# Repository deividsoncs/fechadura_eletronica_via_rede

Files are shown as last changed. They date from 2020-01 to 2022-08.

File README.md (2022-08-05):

# FechaduraEletronicaREDE
# Fechadura Eletrônica com Abertura por RFID ou LOGIN / SENHA com registro centralizado em bd MySql.

Prosposta desse sistema é automatizar entradas/e ou saída de edificações com acionamento via cartão/tag RFID, 
seguido ou não de entrada de senha via teclado númérico. 

1) Usuário aproxima tag RFID de sensor;
2) Módulo de leitura conectado a rede ethernet faz pesquisa em bd MYSQL;
3) Apresenta mensagem customizada bem-vindo [Fulano] ao portador da tag;
4) Portador da tag regista senha de acesso [opcional]
5) Sistema permite o acesso desbloqueando porta eletromagnética;
6) Log é resgistrado em banco, pessoa, data e hora e porta de acesso.

tecnologias: arduino + módulo ethernet, linguagem C, atuadores (ex.: eletroímã).

@Author: Deividson Calixto da Silva.

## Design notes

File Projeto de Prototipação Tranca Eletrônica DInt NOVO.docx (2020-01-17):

Projeto de Prototipação Tranca Eletrônica DINT.

Objetivo:

Projeto contempla a prototipação de uma fechadura eletrônica, com trava eletromecânica e acionamento por leitura de cartões de acesso (TAGS) RFID e SENHA ou RG e SENHA via teclado numérico, onde os usuários serão registrados em um banco de dados. O controle da entrada dos usuários pode ser visualizado através de um histórico de acesso. Sendo o usuário adicionado em uma lista de usuários relacionado a uma TAG RFID/RG único(s). Gerenciamento de usuários centralizado juntamente com histórico de acessos de entradas.

Funções contempladas:

1) Controle de acesso e histórico de quem entrou na porta N;
2) Controle feito por TAG/RG e Senha individual;
3) Histórico de acessos via aplicação web;
4) Gerenciamento centralizado dos usuários em banco de dados MySQL (Aplicação WEB);
5) Botoeira interna de abertura da porta.

Fluxograma de funcionamento:

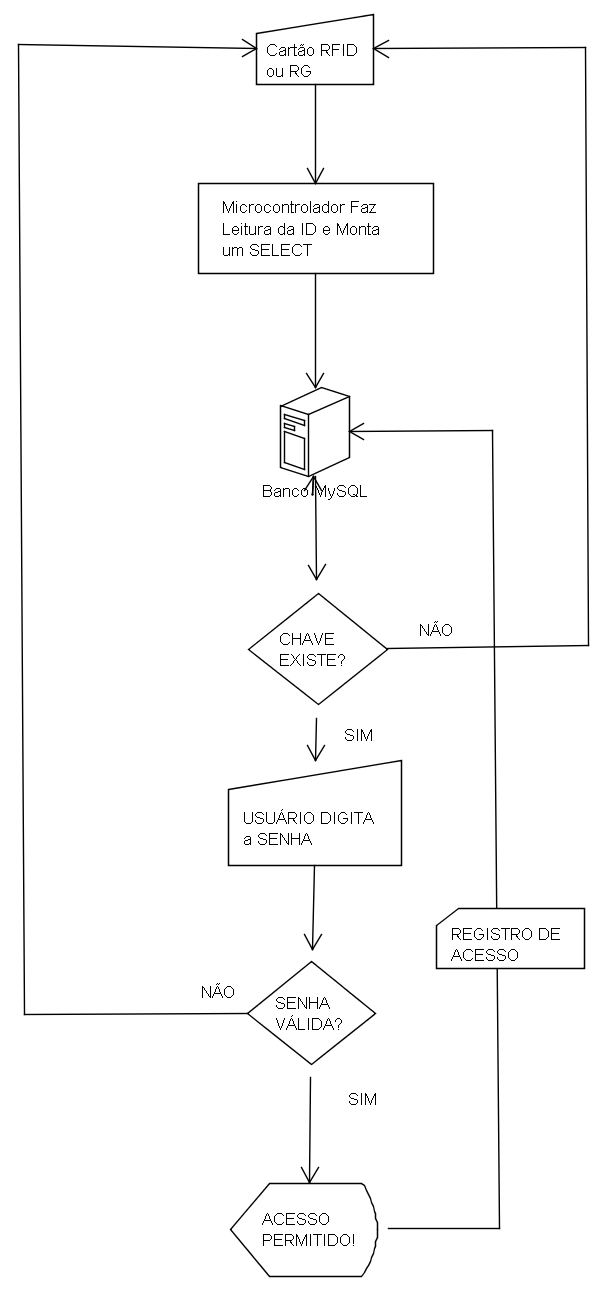
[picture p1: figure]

Imagem 1 - fluxograma

Desenvolvimento:

A) Será desenvolvido um sistema embarcado (Firmware), em linguagem C, para o micro controlador (AtMega2560) realizar as seguintes funções:
1) Leitura de cartão RFID (ou RG) e teclado numérico;
2) Integração do Micro controlador com o protocolo Ethernet, realizando a consulta no banco de retornando com resultado encontrado;
3) Acionamento do relé da fechadura eletromecânica;
4) Criação de uma tabela no banco de dados MySQL (ex.: ID - SENHA NUMERICA – CHAVE RFID – MATRICULA);
5) Registro em Tabela do histórico de entradas.
B) Será desenvolvida uma aplicação web para gerenciamento dos usuários, com as seguintes funcionalidades:
1) Cadastro, edição, exclusão de usuários;
2) Consulta ao histórico de entradas dos usuários;

Exemplo de histórico:

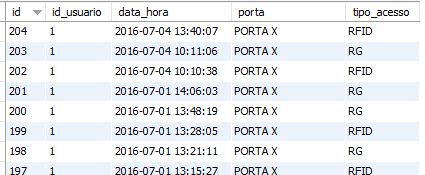
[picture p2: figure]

Imagem 2 - São armazenadas somente as entradas na edificação contemplada.

Dependências necessárias para funcionamento:

1) Rede de intranet DINT(Conexão Ethernet);
2) Servidor de banco de dados MySQL;
3) Alimentação de 12 Vdc, para fechadura eletro mecânica e Microcontrolado e seus afins.

Conclusão:

Projeto proposto contempla um sistema gerenciado e centralizado dos usuários que terão acesso à edificação, possibilitando um histórico das entradas conforme Imagem 2, sistema possibilita entrada de dados por meio do RG ou TAG RFID, atrelado a uma senha de escolha do usuário de 4 dígitos , tornando a aplicação segura e com boa usabilidade, dependendo para sua operação da estabilidade da rede de intranet da DINT, servidor de banco de dados MySQL e Alimentação 12 Vdc. Em casa do falta de energia o acesso se dará por meio da chave. Sendo assim o projeto segue de maneira a providenciar uma solução de baixo custo para o problema proposto, tendo em vista que as soluções do mercado que visam gerenciamento centralizado de usuários são altamente custosas e muita das vezes não vem com todo aparato necessário dependendo de fechaduras eletromagnéticas que são vendidas separadamente, tornando-os ainda mais caros.

Descrição | Quantidade | Imagem

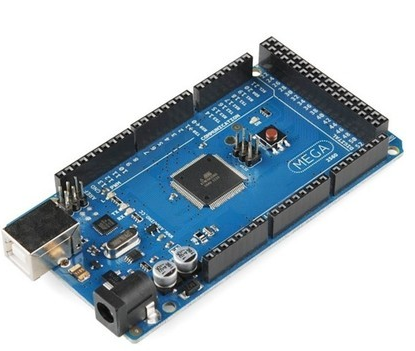
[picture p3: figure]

Arduino Mega 2560 R3 + Cabo Usb para Arduino; Disponível em: http://www.eletrogate.com/pd-88b37-mega-2560-r3-cabo-usb-para-arduino.html?ct=6fb46&p=1&s=1 | 4

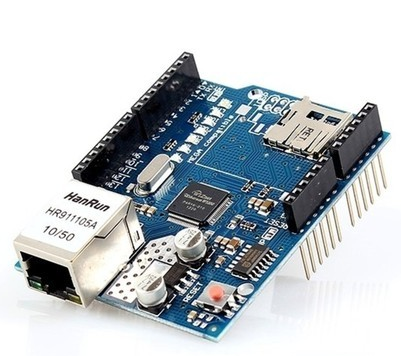
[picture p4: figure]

Ethernet Shield W5100 para Arduino Disponível em: http://www.eletrogate.com/pd-88c9c-ethernet-shield-w5100-para-arduino.html?ct=ae595&p=1&s=1 | 4

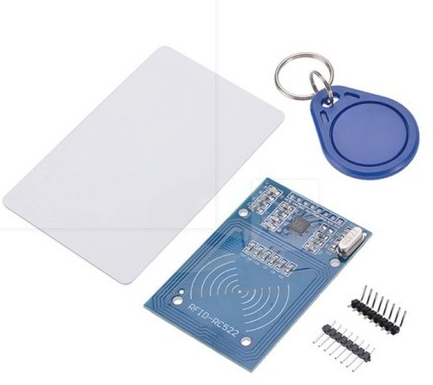
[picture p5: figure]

Kit Módulo Rfid Mfrc522 13,56 Mhz Disponível em: http://www.eletrogate.com/pd-8e3aa-kit-modulo-rfid-mfrc522-13-56-mhz.html?ct=&p=1&s=1 | 4

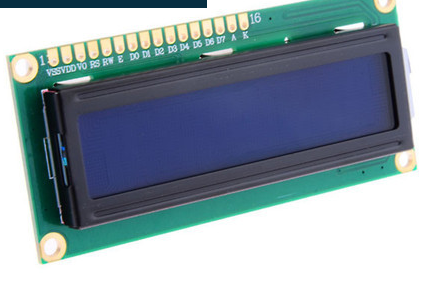
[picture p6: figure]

Display Lcd 16x2 com Backlight | 4
Led Difuso 5mm Amarelo | 4
Led Difuso 5mm Verde | 4
Led Difuso 5mm Vermelho | 4
Diodo Retificador 1N4007 | 4

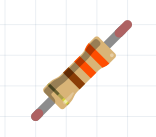
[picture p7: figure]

Resistor 300 Ohms | 12
Resistor 100 Ohms | 8

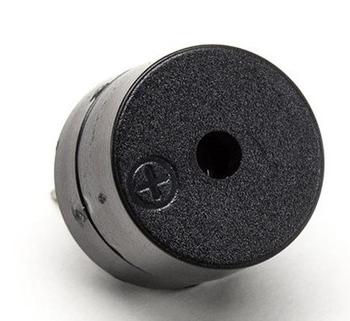
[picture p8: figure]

Buzzer ativo 5 Volts | 4

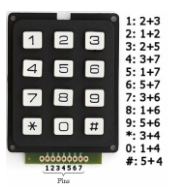
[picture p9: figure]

Teclado Matricial 12 teclas, de 7 Fios/Pinos, Obs.: Não pode ser o tipo membrana, por causa da fragilidade. Disponível em: https://www.robocore.net/modules.php?name=GR_LojaVirtual&prod=164 | 4

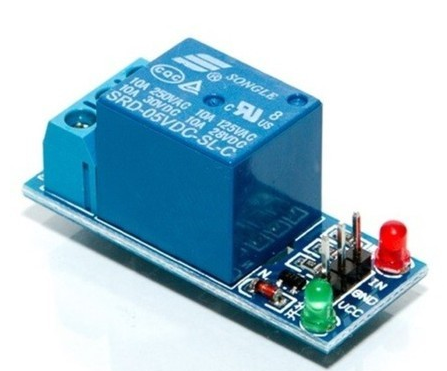
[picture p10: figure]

Módulo Relé 1 Canal 5v Disponível em: http://www.eletrogate.com/pd-1a1bd2-modulo-rele-1-canal-5v.html?ct=&p=1&s=1 | 4

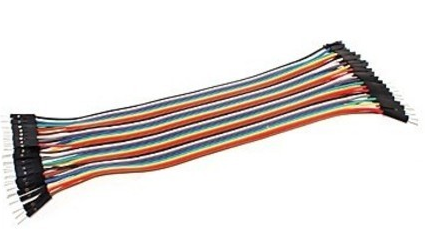
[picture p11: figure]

Fio de 1mm de diâmetro, nas cores AZUL, AMARELO, VERDE, BRANCO e LARANJA | 4 metros de cada

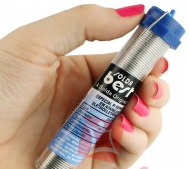
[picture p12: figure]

Estanho para Solda / Fio de Solda 1.0mm - Tubo de 25g | 2

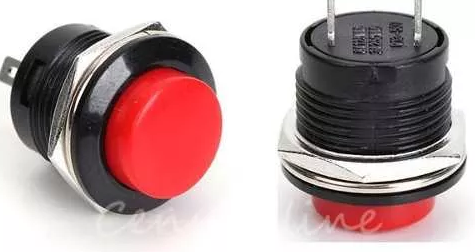
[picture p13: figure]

Botoeira Push Button Normal Aberta 3a 250 V, com rosca | 4

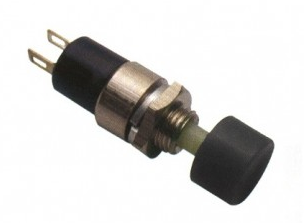
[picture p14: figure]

Chave Push Button Normal Aberta - 2T – Preta, com rosca. | 4
Porta fusível com rabicho + fusível de 1,5A | 4

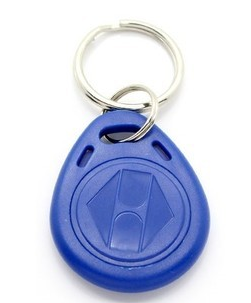
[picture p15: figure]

Tag Chaveiro Rfid Programável Mifare 1k 13,56Mhz Obs.: Atenção com a frequência de 13,56MHz | 120

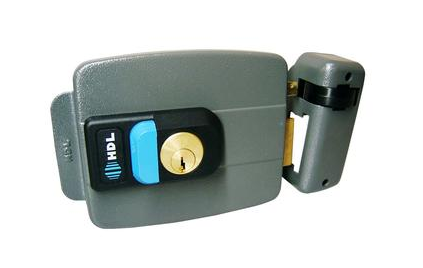
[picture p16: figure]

Fechadura Elétrica Hdl C-90 Dupla com Botao Interno, Porta que abre para dentro. | 3

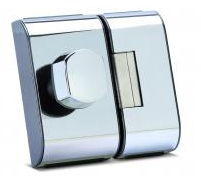
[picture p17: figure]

Fechadura PV-90 2R – Cromada para duas folhas de vidro, com acionamento 12 Vdc, para recorte padrão do mercado, com maçaneta interna. | 1

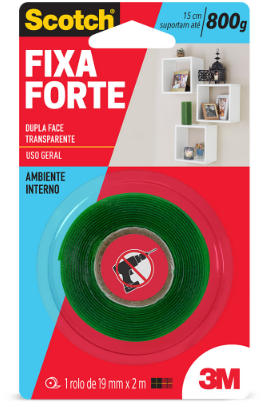
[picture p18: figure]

Fita adesiva dupla face Fixa Forte 19mmx2m | 1

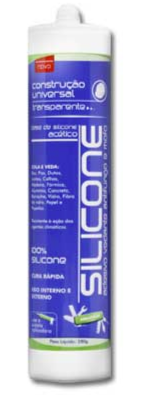
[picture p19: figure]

Silicone Acético Incolor Tubo 280g | 1

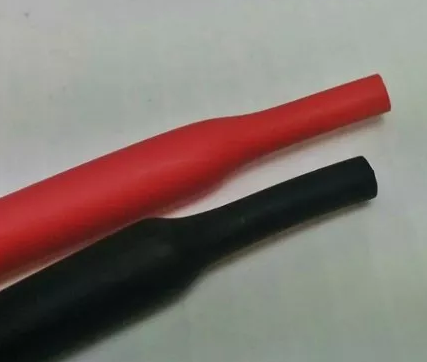
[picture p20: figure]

Espaguetes Isolante Termo Retratil 4mm Vermelho E Preto 5mts | 5 metros

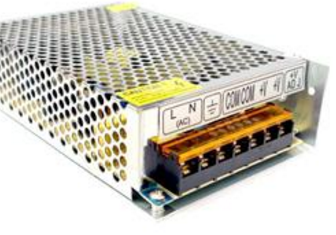
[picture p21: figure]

Fonte chaveada estabilizada 12Vdc 5A 60W | 4

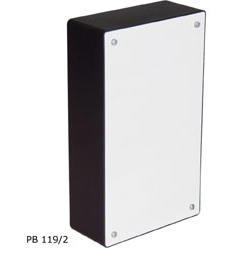
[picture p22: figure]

Caixa Patola PB-119/2 52x110x190 Com tampa fixação pro parafusos (pode ser outra, porém não inferior as medidas e nem superior a 20 mm de diferença) Disponível em: http://www.soldafria.com.br/caixa-patola-pb-1192-52x110x190-p-486.html | 4

Tabela 1 – Componentes necessários.

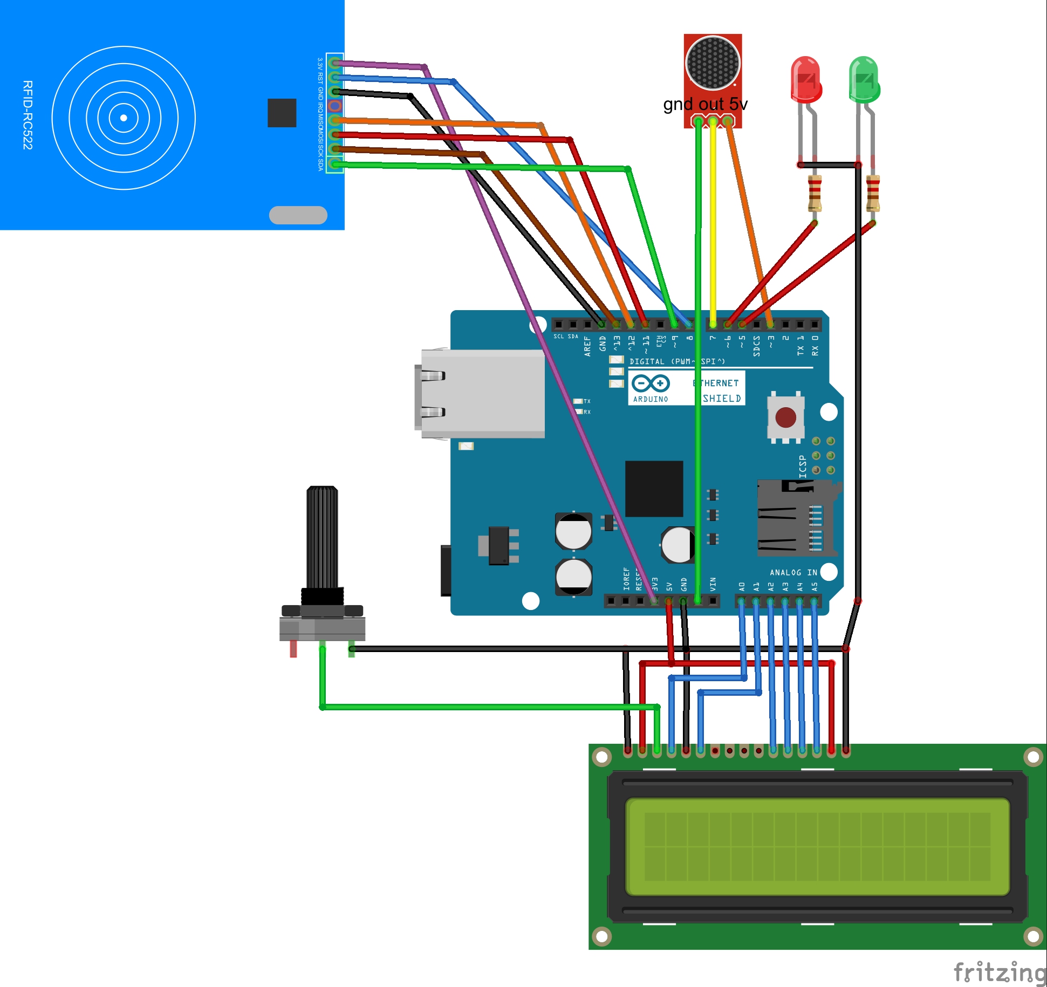
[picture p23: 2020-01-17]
Esquemas/connection schematic.jpg

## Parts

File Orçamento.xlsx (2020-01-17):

Descrição | Quantidade | Valor(Unidade)
Arduino Mega 2560 R3 + Cabo Usb para Arduino; | 4 | R$86.00 |  | Valor Porta Normal | R$546.41
Disponível em: |  |  |  | Valor Porta Vidro | R$607.07
http://www.eletrogate.com/pd-88b37-mega-2560-r3-cabo-usb-para-arduino.html?ct=6fb46&p=1&s=1 |  |  |  | Item gerais de montagem | R$101.90
Ethernet Shield W5100 para Arduino | 4 | R$59.00 |  | Fretes separados aproximado | R$130.00
Disponível em: |  |  |  | TAGS | R$358.80
http://www.eletrogate.com/pd-88c9c-ethernet-shield-w5100-para-arduino.html?ct=ae595&p=1&s=1
Kit Módulo Rfid Mfrc522 13,56 Mhz | 4 | R$50.00
Disponível em:
http://www.eletrogate.com/pd-8e3aa-kit-modulo-rfid-mfrc522-13-56-mhz.html?ct=&p=1&s=1
Display Lcd 16x2 com Backlight | 4 | R$18.00
Led Difuso 5mm Amarelo | 4 | R$1.00
Led Difuso 5mm Verde | 4 | R$1.00
Led Difuso 5mm Vermelho | 4 | R$1.00
Diodo Retificador 1N4007 | 4 | R$3.00
Resistor 300 Ohms | 12 | R$3.00
Resistor 100 Ohms | 8 | R$2.00
Buzzer ativo 5 Volts | 4 | R$2.50
Teclado Matricial 12 teclas, de 7 Fios/Pinos, Obs.: Não pode ser o tipo membrana, por causa da fragilidade. | 4 | R$35.00
Disponível em: https://www.robocore.net/modules.php?name=GR_LojaVirtual&prod=164
Módulo Relé 1 Canal 5v | 4 | R$12.90
Disponível em:
http://www.eletrogate.com/pd-1a1bd2-modulo-rele-1-canal-5v.html?ct=&p=1&s=1
Fio de 1mm de diâmetro, nas cores AZUL, AMARELO, VERDE, BRANCO e LARANJA (4 metros cada) | 4 metros de cada | R$20.00
Estanho para Solda / Fio de Solda 1.0mm - Tubo de 25g | 2 | R$20.00
Botoeira Push Button Normal Aberta 3a 250 V, com rosca | 4 | R$5.00
Chave Push Button Normal Aberta - 2T – Preta, com rosca. | 4 | R$5.00
Porta fusível com rabicho + fusível de 1,5A | 4 | R$6.00
Tag Chaveiro Rfid Programável Mifare 1k 13,56Mhz | 120 | R$2.99
 |  |  | Valor de ML
Obs.: Atenção com a frequência de 13,56MHz
Fechadura Elétrica Hdl C-90 Dupla com Botao Interno, Porta que abre para dentro. | 3 | R$203.11
Fechadura PV-90 2R – Cromada para duas folhas de vidro, com acionamento 12 Vdc, para recorte padrão do mercado, com maçaneta interna. | 1 | R$268.77
Fita adesiva dupla face Fixa Forte 19mmx2m | 1 | R$18.00
Silicone Acético Incolor Tubo 280g | 1 | R$14.00
Espaguetes Isolante Termo Retratil 4mm Vermelho E Preto 5mts | 5 metros | R$9.90
Fonte chaveada estabilizada 12Vdc 5A 60W | 4 | R$35.00
Caixa Patola PB-119/2 52x110x190 | 4 | R$17.90
Com tampa fixação pro parafusos
(pode ser outra, porém, não inferior as medidas e nem superior a 20 mm de diferença)
Disponível em:
http://www.soldafria.com.br/caixa-patola-pb-1192-52x110x190-p-486.html
Parafusos e Buchas??? | ??? | R$20.00

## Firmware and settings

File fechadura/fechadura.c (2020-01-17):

/**
    Protótipo de Fechadura Eletrônica controlada
    autor: Deividson Calixto da Silva
*/
#include <SPI.h>
#include <Ethernet.h>
#include <MFRC522.h>
#include <LiquidCrystal.h>
#include <ICMPPing.h>
#include <util.h>
#include <Key.h>
#include <Keypad.h>
#include <avr/wdt.h>
#include <sha1.h>
#include <mysql.h>
#include <stdlib.h>


/* Configurações de Ethernet */
byte macAddr[] = { 0xDE, 0xAD, 0xBE, 0xEF, 0xFE, 0xED };
IPAddress servidorSQL(10, 0, 10, 203);
IPAddress meuIP(10, 0, 10, 32);
IPAddress meuDNS(10, 0, 10, 10);
IPAddress gw(10, 0, 10, 1);
IPAddress mask(255, 255, 255, 0);

//conector do banco mysql
Connector my_conn;

//usuário Banco
char user[] = "arduino2";
char password[] = "123456"; //Senha será convertida usando sha1 na transmissão!

const char PORTA_ATUACAO[] = "PORTA N";

char SELECT_RFID[100] = "SELECT id, SUBSTRING(nome,1,16), senha FROM arduino_db.usuarios WHERE(chave like '%s');";
char SELECT_RG[100] = "SELECT id, SUBSTRING(nome,1,16), senha, rg FROM arduino_db.usuarios WHERE(rg like '%s');";
//INSERT de acionamento da porta
char INSERT_HISTORICO_RFID[180] = "INSERT INTO arduino_db.historico (porta, data_hora, id_usuario, tipo_acesso) VALUES ('%s', now(), %d, 'RFID');";
char INSERT_HISTORICO_RG[180] = "INSERT INTO arduino_db.historico (porta, data_hora, id_usuario, tipo_acesso) VALUES ('%s', now(), %d, 'RG');";
char QUERY_AUX[180] = "";

//id do usuario resgatando do banco
long idUsuario = 0;
//SELECT sempre retornara os 16 primeiros caracteres do nome.
char *nomeUsuario = (char *)malloc(16 * sizeof(char));
char *senhaBco = (char *)malloc(4 * sizeof(char));
String strChave = "";

unsigned long millisAnteriorRFID = 0;
unsigned long millisAtualRFID = 0;
unsigned long millisAnteriorConex = 0;
unsigned long millisAtualConex = 0;
unsigned long millisAnteriorlSenha = 0;
unsigned long millisAtualRenovaConex = 0;
unsigned long millisAnteriorRenovaConex = 0;

/*
  X minutos checar se está conectado e faz um HAND SHAKE no banco
  renovando a conexão evitando que o MySQL de um Kill Connection.
*/
const long TEMPO_RENOVA_CONEX = 3600000; //uma hora 3600000
//Tempo de execução de leitura do shield RFID
const int TEMPO_LED_RFID = 500;
//Tempo de checagem se a conexão, senão reboota o atmega.
const long TEMPO_VERIFICA_CONEX = 120000;
//10 Seg. Tempo que o usuário tem para digitar a senha.
const int TEMPO_LEITURA_SENHA = 10000;

//Led de leitura efetuada do cartão RFID
const int LED_LEITURA_RFID = 24;
//Led de Liberação de acesso;
const int LED_LIB_ACESSO_RFID = 26;
//Led indicado de Acesso Inválido
const int LED_ACESSO_INVALIDO = 22;
//rele de acionamento da porta
const int PORTA_RELE = 36;
//BUZZER;
const int BUZZER = 7;
//Display LCD
const int PINO_PWM_LCD = 6;
//Luz de fundo LCD
const int BACKLIGHT_LED = 25;

//controle de excecução
int parado = 0;
//contador de falhas de conexão
int num_fails = 0;

#define MAX_FAILED_CONNECTS 5
#define ABERTURA_PORTA 1000
#define RST 5
#define SS 53
#define ETH_PIN 10
#define BOTAO_ABRIR 28

//módulo de TAGS de 13,56MHz
MFRC522 mfrc522(SS, RST);

//LiquidCrystal(rs, enable, d4, d5, d6, d7)
LiquidCrystal lcd(31, 30, 32, 33, 34, 35);

//teclado
const byte ROWS = 4;
const byte COLS = 3;
char keys[ROWS][COLS] = {
  {'1', '2', '3'},
  {'4', '5', '6'},
  {'7', '8', '9'},
  {'*', '0', '#'}
};

//byte rowPins[ROWS] = {42, 43, 44, 45};
byte rowPins[ROWS] = {45, 44, 43, 42};

//byte colPins[COLS] = {38, 39, 40};
byte colPins[COLS] = {40, 39, 38};

Keypad keypad = Keypad(makeKeymap(keys), rowPins, colPins, ROWS, COLS);

//Utilizado para realizar o ping
SOCKET pingSocket = 1;
ICMPPing ping(pingSocket, (uint16_t)random(0, 255));
char buffer[256];

void setup() {
  //regula o bounce do teclado
  keypad.setDebounceTime(60);

  //ligação teclado
  //linhas
  pinMode(42, OUTPUT);
  pinMode(43, OUTPUT);
  pinMode(44, OUTPUT);
  pinMode(45, OUTPUT);
  //colunas
  pinMode(38, INPUT);
  pinMode(39, INPUT);
  pinMode(40, INPUT);

  //botoeira de abrir porta
  pinMode(BOTAO_ABRIR, INPUT_PULLUP);


  lcd.begin(16, 2);
  pinMode(PINO_PWM_LCD, OUTPUT);

  //contraste do LCD;
  analogWrite(PINO_PWM_LCD, 60);
  lcd.setCursor(0, 0);
  lcd.write("-+#DINT--PMES#+-");

  //backlight led
  pinMode(BACKLIGHT_LED, OUTPUT);
  digitalWrite(BACKLIGHT_LED, HIGH);

  pinMode(LED_LEITURA_RFID, OUTPUT);
  pinMode(LED_LIB_ACESSO_RFID, OUTPUT);
  pinMode(LED_ACESSO_INVALIDO, OUTPUT);
  //  pinMode(botao_RFID, INPUT_PULLUP);
  pinMode(BUZZER, OUTPUT);
  pinMode(PORTA_RELE, OUTPUT);
  digitalWrite(PORTA_RELE, HIGH);

  digitalWrite(LED_ACESSO_INVALIDO, HIGH);
  digitalWrite(LED_LEITURA_RFID, HIGH);
  digitalWrite(LED_LIB_ACESSO_RFID, HIGH);

  Ethernet.begin(macAddr, meuIP, meuDNS, gw, mask);
  Serial.begin(115200);
  Serial.println("Inicializando...");
  Serial.println("Meu IP: ");
  Serial.println(Ethernet.localIP());
  lcd.setCursor(0, 1);
  lcd.write("Iniciando.......");
  delay(1000);
  digitalWrite(LED_ACESSO_INVALIDO, LOW);
  digitalWrite(LED_LEITURA_RFID, LOW);
  digitalWrite(LED_LIB_ACESSO_RFID, LOW);

  lcd.setCursor(14, 1);
  lcd.write("OK");
  delay(1000);

  //lcd.clear();
  //conecta ao banco de dados
  conectar();

  selecionaRFID();
  SPI.begin();
  mfrc522.PCD_Init();
  delay(1000);

  //coloco o watchDog por * segundos;
  wdt_enable(WDTO_8S);
}

void loop() {
  //reset do contador do watchdog, estou vivo!
  wdt_reset();

  lcd.setCursor(0, 0);
  lcd.write("-+#DINT--PMES#+-");
  lcd.setCursor(0, 1);
  //lcd.write("0123456789abcdef");
  lcd.write("Aproxime Cartao!");

  //desliga backlight
  digitalWrite(BACKLIGHT_LED, LOW);

  millisAtualRFID = millis();
  millisAtualConex = millis();
  millisAtualRenovaConex = millis();

  //Evitar overflow do millis()
  if (millisAtualRFID < millisAnteriorRFID) {
    millisAnteriorRFID = millisAtualRFID;
  }
  if (millisAtualConex < millisAnteriorConex) {
    millisAnteriorConex = millisAtualConex;
  }
  if (millisAtualRenovaConex < millisAnteriorRenovaConex) {
    millisAnteriorRenovaConex = millisAtualRenovaConex;
  }

  //##############################################################################################
  //##################################Entrada por Cartão RFID#####################################
  //##############################################################################################

  //Período de leitura do RFID.
  if (millisAtualRFID - millisAnteriorRFID >= TEMPO_LED_RFID) {
    selecionaRFID();
    //marco o tempo o qual realizei a tarefa
    millisAnteriorRFID = millisAtualRFID;
    if (digitalRead(LED_LEITURA_RFID) == LOW) {
      digitalWrite(LED_LEITURA_RFID, HIGH);
    } else {
      digitalWrite(LED_LEITURA_RFID, LOW);
    }

    if (mfrc522.PICC_IsNewCardPresent()) {
      if (mfrc522.PICC_ReadCardSerial()) {
        digitalWrite(BACKLIGHT_LED, HIGH);
        Serial.println("Memoria Livre (ANTES LEITURA DO CARTÃO):");
        Serial.println(get_free_memory());
        /*
          // Show some details of the PICC (that is: the tag/card)
          Serial.print(F("Card UID:"));
          //dump_byte_array(mfrc522.uid.uidByte, mfrc522.uid.size);
          Serial.println();
          Serial.print(F("PICC type: "));
          MFRC522::PICC_Type piccType = mfrc522.PICC_GetType(mfrc522.uid.sak);
          Serial.println(mfrc522.PICC_GetTypeName(piccType));
        */
        //Serial.println("Cartao detectado!");
        //Mostra UID na serial
        //Serial.print("UID da tag :");
        strChave = "";
        char chave[mfrc522.uid.size];
        for (byte i = 0; i < mfrc522.uid.size; i++) {
          //Serial.print(mfrc522.uid.uidByte[i] < 0x10 ? "0" : "");
          //Serial.print(mfrc522.uid.uidByte[i], HEX);
          strChave.concat(String(mfrc522.uid.uidByte[i] < 0x10 ? "0" : ""));
          strChave.concat(String(mfrc522.uid.uidByte[i], HEX));
          //chave[i] = toupper(HEX);
        }
        //Serial.println("");
        //paro e encerro o RFID e Habilito do Ethernet
        mfrc522.PICC_HaltA();
        //mfrc522.PCD_StopCrypto1();
        //desabilito RFID e habilito a Ethernet
        selecionaETH();
        //Serial.println("conteudo:");
        //Serial.println(conteudo);
        //Serial.println("");
        //Eliminar excesso de caracteres, evitar um possível overflow
        for (byte i = 0; i < 12; i++) {
          chave[i] = toupper(strChave[i]);
          //Serial.print(chave[i]);
        }

        tone(BUZZER, 1500, 200);

        if (my_conn.is_connected()) {
          wdt_reset();
          //my_conn.cmd_query("SELECT * FROM usuarios");
          //my_conn.show_results();

          //      String Final, Select do RFID, CHAVE
          sprintf(QUERY_AUX, SELECT_RFID, chave);
          Serial.println(QUERY_AUX);
          my_conn.cmd_query(QUERY_AUX);
          my_conn.get_columns();
          row_values *row = NULL;
          row = my_conn.get_next_row();

          do {
            if (row != NULL) {
              //resgatando os dados do usuário encontrado
              idUsuario = atol(row->values[0]);
              nomeUsuario = row->values[1];
              senhaBco = row->values[2];
              //Serial.println(nomeUsuario);
              //my_conn.show_results();
              lcd.setCursor(0, 1);
              lcd.write("   BEM VINDO!   ");
              delay(1000);
              lcd.setCursor(0, 1);
              lcd.write("                ");
              lcd.setCursor(0, 1);
              lcd.write(nomeUsuario);
              delay(1000);
              lcd.setCursor(0, 1);
              lcd.write("Senha:          ");
              if (senhaBco != NULL) {
                char senhaDig[] = "0000";
                byte c = 0;
                //Serial.println("Digite a senha");
                unsigned long millisAnteriorlSenha = millis();
                //loop de leitura de senha, lê o teclado enquanto o tempo não esgotar ou 4 digitos serem digitados.
                do {
                  wdt_reset();
                  //caso o usuário não termine de digitar a senha no tempo estipulado sai do loop
                  if (millis() - millisAnteriorlSenha > TEMPO_LEITURA_SENHA) {
                    break;
                  } else {
                    char keyPress = keypad.getKey();
                    if (keyPress != NO_KEY) {
                      tone(BUZZER, 1500, 200);
                      lcd.setCursor(6 + c, 1);
                      lcd.write("*");
                      senhaDig[c] = keyPress;
                      //Serial.print(keyPress);
                      c++;
                    }
                  }
                } while (c < 4);
                //verifico a senha
                if (strcmp(senhaBco, senhaDig) == 0) {
                  //Faço uma espécie de preparedStatement para execução da Query do Histórico;
                  sprintf(QUERY_AUX, INSERT_HISTORICO_RFID, PORTA_ATUACAO, idUsuario);
                  //inserção na tabela de hitórico!
                  my_conn.cmd_query(QUERY_AUX);
                  acessoPermitido();
                } else {
                  acessoNegado();
                }
              } else {
                acessoNegado();
              }
            } else {
              acessoNegado();
            }
            row = NULL;
          } while (row != NULL);

          my_conn.free_row_buffer();
          //Libera o buffer de colunas;
          my_conn.free_columns_buffer();
          my_conn.clear_ok_packet();

          Serial.println("Memoria Livre (DEPOIS CONSULTA):");
          Serial.println(get_free_memory());
          num_fails = 0;
        } else {
          //Reset para restauração, visto que não está conseguindo reconectar pelo conectar();
          soft_reset();
        }
      }
    }
  }
  //##############################################################################################
  //########################################PING de CONEXAO#######################################
  //##############################################################################################

  if (millisAtualConex - millisAnteriorConex >= TEMPO_VERIFICA_CONEX) {
    millisAnteriorConex = millisAtualConex;
    selecionaETH();
    //Serial.println("----------------");
    //Serial.print("| PING ? ");
    ICMPEchoReply echoReply = ping(servidorSQL, 4);
    delay(30);
    if (echoReply.status == SUCCESS) {
      Serial.print(">");
      //Serial.println("PONG :) |");
      //Serial.println("----------------");
    } else {

      //tentan novamente
      echoReply = ping(servidorSQL, 4);
      delay(30);
      if (echoReply.status == SUCCESS) {
        Serial.print(">");
      } else {
        Serial.println(":'( Resetando  |");
        Serial.println("----------------");
        digitalWrite(BACKLIGHT_LED, HIGH);
        lcd.setCursor(0, 0);
        lcd.write("ERRO SEM PING!!!");
        lcd.setCursor(0, 1);
        lcd.write("BANCO||REDE FORA");
        delay(4000);
        //Uso soft_reset pois reconecta mais rapido do que ficar tentando pelo conectar()
        soft_reset();
      }
    }
  }

  //##############################################################################################
  //####################################RENOVA CONEXAO MYSQL######################################
  //##############################################################################################
  if (millisAtualRenovaConex - millisAnteriorRenovaConex >= TEMPO_RENOVA_CONEX) {
    selecionaETH();
    millisAnteriorRenovaConex = millisAtualRenovaConex;
    if (my_conn.is_connected()) {
      num_fails = 0;
      Serial.println("-----------------------");
      Serial.println("Renovando conexao MySQL!");
      //Atualiza a conexão para o MySQL não derruba-la
      my_conn.cmd_query("SELECT @@version");
      my_conn.show_results();
      Serial.println("-----------------------");
    } else {
      Serial.println("Resetando");
      soft_reset();
    }
  }

  //##############################################################################################
  //####################################ABERTURA POR BOTOEIRA#####################################
  //##############################################################################################
  if (digitalRead(BOTAO_ABRIR) == LOW) {
    delay(100);
    acessoPermitido();
  }

  //##############################################################################################
  //##################################ENTRADA POR RG e SENHA######################################
  //##############################################################################################

  char keyPress = keypad.getKey();
  if (keyPress == '#') {
    Serial.println("Memoria Livre RG (ANTES CONSULTA):");
    Serial.println(get_free_memory());
    digitalWrite(BACKLIGHT_LED, HIGH);
    tone(BUZZER, 1500, 200);
    lcd.setCursor(0, 1);
    lcd.write("Digite RG:      ");
    unsigned long millisAnteriorRG = millis();
    char keyRG;
    String strRG = "";
    byte tamRG = 0;
    //Serial.println("RG: ");
    do {
      wdt_reset();
      //caso o usuário não termine de digitar rg no tempo estipulado sai do loop
      if (millis() - millisAnteriorRG > TEMPO_LEITURA_SENHA) {
        break;
      } else {
        keyRG = keypad.getKey();
        if (keyRG == '#' || keyRG == '*') {
          break;
        }
        if (keyRG != NO_KEY && keyRG != '#' && keyRG != '*') {
          //Serial.print(keyRG);
          tone(BUZZER, 1500, 200);
          lcd.setCursor(10 + tamRG, 1);
          lcd.write(keyRG);
          tamRG++;
          strRG.concat(keyRG);
        }
      }
      if (tamRG >= 7) {
        keyRG = '#';
        break;
      }
    } while (keyRG != '#' || keyRG != '*');

    char *rgAux = new char[strRG.length() + 1];
    strcpy(rgAux, strRG.c_str());

    //Se confirmou com a tecla #
    if (keyRG == '#' && rgAux != NULL) {
      selecionaETH();
      if (my_conn.is_connected()) {
        //      String Final, Select do RFID, CHAVE
        sprintf(QUERY_AUX, SELECT_RG, rgAux);

        delete [] rgAux;

        Serial.println(QUERY_AUX);
        my_conn.cmd_query(QUERY_AUX);
        my_conn.get_columns();
        row_values *row = NULL;
        row = my_conn.get_next_row();
        do {
          if (row != NULL) {
            //resgatando os dados do usuário encontrado
            idUsuario = atol(row->values[0]);
            nomeUsuario = row->values[1];
            senhaBco = row->values[2];
            //Serial.println(nomeUsuario);
            //my_conn.show_results();
            lcd.setCursor(0, 1);
            lcd.write("   BEM VINDO!   ");
            delay(1000);
            lcd.setCursor(0, 1);
            lcd.write("                ");
            lcd.setCursor(0, 1);
            lcd.write(nomeUsuario);
            delay(1000);
            lcd.setCursor(0, 1);
            lcd.write("Senha:          ");
            //Serial.println("Serial!");

            if (senhaBco != NULL) {
              char senhaDig[] = "0000";
              //contador
              byte c = 0;
              //Serial.println("Digite a senha");
              unsigned long millisAnteriorlSenha = millis();
              //loop de leitura de senha, lê o teclado enquanto o tempo não esgotar ou 4 digitos serem digitados.
              do {
                wdt_reset();
                //caso o usuário não termine de digitar a senha no tempo estipulado sai do loop
                if (millis() - millisAnteriorlSenha > TEMPO_LEITURA_SENHA) {
                  break;
                } else {
                  char keyPress = keypad.getKey();
                  if (keyPress != NO_KEY) {
                    tone(BUZZER, 1500, 200);
                    lcd.setCursor(6 + c, 1);
                    lcd.write("*");
                    senhaDig[c] = keyPress;
                    //Serial.print(keyPress);
                    c++;
                  }
                }
              } while (c < 4);
              //verifico a senha
              if (strcmp(senhaBco, senhaDig) == 0) {
                //Serial.println(">>>>>>>>>>>>> SENHAS IGUAIS");
                //Faço uma espécie de preparedStatement para execução da Query do Histórico;
                sprintf(QUERY_AUX, INSERT_HISTORICO_RG, PORTA_ATUACAO, idUsuario);
                //inserção na tabela de hitórico!
                my_conn.cmd_query(QUERY_AUX);
                acessoPermitido();

              } else {
                //Serial.println(">>>>>>>>>>>>> SENHAS DIFERENTES");
                acessoNegado();
              }
            } else {
              acessoNegado();
            }

          } else {
            acessoNegado();
          }
          //free(row);
          row = NULL;
        } while (row != NULL);
        //Libera o buffer de linhas
        my_conn.free_row_buffer();
        //Libera o buffer de colunas;
        my_conn.free_columns_buffer();
        my_conn.clear_ok_packet();
        Serial.println("Memoria Livre RG (DEPOIS CONSULTA):");
        Serial.println(get_free_memory());
        num_fails = 0;
      } else {
        //Reset para restauração, visto que não está conseguindo reconectar pelo conectar();
        soft_reset();
      }
    }
  }
}

void acessoPermitido() {
  digitalWrite(LED_LIB_ACESSO_RFID, HIGH);
  //Serial.println("Entrada Liberada!");
  //delay de abertura
  digitalWrite(PORTA_RELE, LOW);
  tone(BUZZER, 2900, 300);
  delay(ABERTURA_PORTA);
  digitalWrite(PORTA_RELE, HIGH);
  digitalWrite(LED_LIB_ACESSO_RFID, LOW);
  //digitalWrite(PORTA_RELE, HIGH);
}

void acessoNegado() {
  //Serial.println("Acesso nao autorizado! Chave nao encontrada!");
  lcd.setCursor(0, 1);
  lcd.write(" NAO AUTORIZADO ");
  for (byte c = 0; c <= 1; c++) {
    tone(BUZZER, 2900);
    digitalWrite(LED_ACESSO_INVALIDO, HIGH);
    delay(400);
    digitalWrite(LED_ACESSO_INVALIDO, LOW);
    noTone(BUZZER);
  }
}

//##############################################################################################
//##################################Conexão com Banco###########################################
//##############################################################################################
void  conectar() {
  selecionaETH();
  while (!my_conn.is_connected()) {
    Serial.println("Conectando ao Banco...");
    lcd.setCursor(0, 1);
    lcd.write("Conectando......");
    if (my_conn.mysql_connect(servidorSQL, 3306, user, password)) {
      delay(500);
      my_conn.cmd_query("USE arduino_db");
      toqueConexao();
      lcd.setCursor(14, 1);
      lcd.write("OK");
    } else {
      my_conn.disconnect();
      num_fails++;
      Serial.println("Falha ao Conectar!");
      if (num_fails == MAX_FAILED_CONNECTS) {
        Serial.println("Falha ao tentar conectar por 5x... Reiniciando Sistema...");
        lcd.setCursor(0, 1);
        lcd.write("Falha Conexao-BD)");
        delay(2000);
        lcd.setCursor(0, 1);
        lcd.write("Reiniciando Sist");
        tone(BUZZER, 1900, 2000);
        delay(2000);
        soft_reset();
      }
    }
  }
}
//seleciona o SPI para utilização do Shield Ethernet
void selecionaETH() {
  //desabilita o RFID
  digitalWrite(SS, HIGH);
  //habilitar Ethernet
  digitalWrite(ETH_PIN, LOW);
}
//seleciona o SPI para utilização do Shield RFID
void selecionaRFID() {
  //desabilita Ethernet
  digitalWrite(ETH_PIN, HIGH);
  //habilita RFID
  digitalWrite(SS, LOW);
}

//toque que precede a conexão ao banco
void toqueConexao() {
  for (int i = 0; i <= 2500; i += 500) {
    tone(BUZZER, i + 1000);
    delay(400);
  }
  noTone(BUZZER);
}

//reset via comando
void soft_reset() {
  asm volatile("jmp 0");
}


int get_free_memory() {
  extern char __bss_end;
  extern char *__brkval;
  int free_memory;
  if ((int)__brkval == 0)
    free_memory = ((int)&free_memory) - ((int)&__bss_end);
  else
    free_memory = ((int)&free_memory) - ((int)__brkval);
  return free_memory;
}
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

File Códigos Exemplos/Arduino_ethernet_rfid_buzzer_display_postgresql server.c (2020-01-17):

#include <SPI.h>
#include <Ethernet.h>
#include <RFID.h>
#include <LiquidCrystal.h>

void make_request(String& id);                                     // make a badge request
void time();                                                       // make a time request to be displayed on the lcd

    // CONFIG ethernet
byte mac[] = {0xDE, 0xAD, 0xBE, 0xEF, 0xFE, 0xED};
byte ip[] = {192, 168, 1, 141};                                    // static arduino IP
byte server[] = {192, 168, 1, 201};                                // static server IP
EthernetClient client;                                             

    // CONFIG RFID
#define SS_PIN 9
#define RST_PIN 8
RFID rfid(SS_PIN, RST_PIN);             

    // CONFIG LCD
LiquidCrystal lcd(A0, A1, A2, A3, A4, A5);

    // delay
unsigned long previousMillis = 0, currentMillis = 0;

void setup()
{    Serial.begin(9600);
     SPI.begin(); 
     rfid.init();
     lcd.begin(16, 2);
     
     lcd.setCursor(0, 0);
     lcd.print(F("Device setup.."));
     
         // disable rfid
     pinMode(9, OUTPUT);
     digitalWrite(9, HIGH);
     
         // disable sd card
     pinMode(4, OUTPUT);
     digitalWrite(4, HIGH);
      
         // enable ethernet
     pinMode(10, OUTPUT);
     digitalWrite(10, LOW); 
     
         // setup buzzer (pin 7)
     pinMode(3, OUTPUT);
     digitalWrite(3, HIGH);
     pinMode(7, OUTPUT);
     digitalWrite(7, HIGH);
     
        // acquiring ip without dhcp
     Ethernet.begin(mac, ip);
     delay(1000);
     lcd.setCursor(14, 0);
     lcd.print(F("OK"));
     delay(1000);
     lcd.clear();
     lcd.setCursor(0, 0);
     lcd.print(F("     ICAS94     "));
     lcd.setCursor(0, 1);
     lcd.print(F("Waiting server.."));
}

void loop()
{   // if a card is read, then get the id from the card and call make_request() for validation 
	if (rfid.isCard())
     {    if (rfid.readCardSerial())
          {    String id = "";
               id += rfid.serNum[0];
               id += rfid.serNum[1];
               id += rfid.serNum[2];
               id += rfid.serNum[3];
               id += rfid.serNum[4];
               //lcd.setCursor(0, 0);
               //lcd.print(id);
               //delay(7000);
               make_request(id);
               lcd.setCursor(0, 0);
               lcd.print(F("     ICAS94     "));
               lcd.setCursor(0, 1);         
          }
     }
	
     currentMillis = millis();
	 
	//	fix the currentMillis overflow problem
    if(currentMillis<previousMillis)
        previousMillis = currentMillis;
		 
	// if a certain amount of time has passed (2 seconds), calculate the time to be displayed on the lcd calling time()
    if(currentMillis-previousMillis >= 2000)
    {   previousMillis = currentMillis;
        time();
        lcd.setCursor(0, 0);
        lcd.print(F("     ICAS94     "));
    }
}

void make_request(String& id)
{   if (client.connect(server, 80))
    {   // enable buzzer
		digitalWrite(7, LOW);
		
		// create the request pointing to the page under the path apache2/htdocs/index.php (in my case)
         String richiesta = "GET /Timb/index.php?code=";
         richiesta += id;
         richiesta += " HTTP/1.0";
         client.println(richiesta); 
         client.println();
         delay(50);
		 
		/*  create the answer (it's not the best solution, but for my little project is perfect): 
			- after the request has been sent to the server, index.php gets dynamically populated with the content of the database
			- all of the strings to be displayed on the lcd will be created with the structure "XXXanswer;" if i have to display an error, or "XXXanswer." if the request was ok
			- i have to look inside the idex.php for the first occurrance of XXX
			- start reading and storing the chars in the 'answer' variable till ';' or '.' is found
		*/
		
         String risposta = ""; 	// answer variable
         int contatore = 0;
         char c = 'a';
         char c_prec = 'a';
         while(true)
         {    if (client.available())
              {    c = client.read();
                   if(contatore >=3)
                        risposta += c;
                   else
                   {    if(c == 'X')
                        {    if(c_prec == 'X')
                                  contatore++;
                             else
                             {    contatore = 1; 
                                  c_prec = c;
                             }    
                        }
                        else if(c != 'X' && contatore < 3)
                        {    contatore = 0;
                             c_prec = c;
                        }
                   }
              }
			  // if there isn't anything left to be read from the server display the message
              if (!client.connected())
              {    client.stop();
                   /* read the last character of the string:
                           - if i read ';' there must have been and error, then the red led is turned on (on pin 6)
                           - if i read '.' everything is ok and the green led is turned on (on pin 5)
                   */
                   risposta.trim();
                   if(risposta.lastIndexOf(';')>0)
                   {   risposta.replace(';', '\0'); 
                       digitalWrite(6, HIGH);
                   }
                   else
                       digitalWrite(5, HIGH);
					   
					// print on the display
                   lcd.clear();
                   lcd.print(risposta.substring(0, risposta.lastIndexOf('.')));
                   lcd.setCursor(0, 1);
                   lcd.print(risposta.substring(risposta.lastIndexOf('.')+1));
                   delay(1500);
				   
				   // turn off the leds and the buzzer
                   digitalWrite(5, LOW);
                   digitalWrite(6, LOW);
                   digitalWrite(7, HIGH);
                   lcd.clear();
                   break;
              }             
         }
    }  
}
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
